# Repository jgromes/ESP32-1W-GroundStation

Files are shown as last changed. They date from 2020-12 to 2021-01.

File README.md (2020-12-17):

# ESP32-1W-GroundStation
ESP32-based LoRa ground station

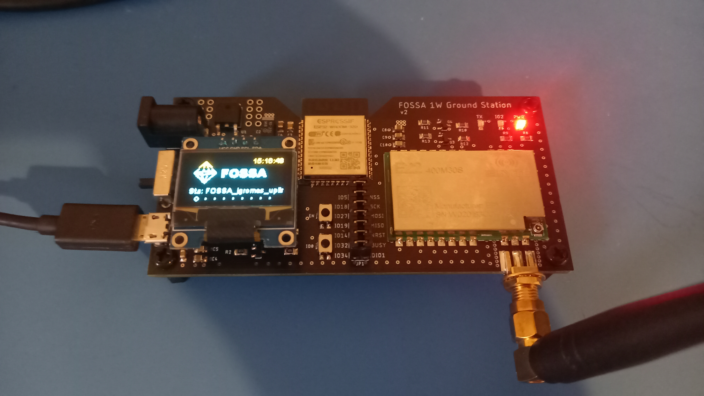
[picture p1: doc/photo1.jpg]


## Features:
* Fully compatible with https://github.com/G4lile0/ESP32-OLED-Fossa-GroundStation
* Radio: Ebyte E22-400M30S (http://www.ebyte.com/en/product-view-news.aspx?id=454)
  * SX1268 with TCXO
  * 1W external PA
  * Automatic Rx/Tx switching
  * IPX and SMA connectors
* OLED display
* Selectable power source (USB/external jack)
* Status LEDs: power, Rx/Tx, ESP32 IO2
* On-board USB/UART convertor

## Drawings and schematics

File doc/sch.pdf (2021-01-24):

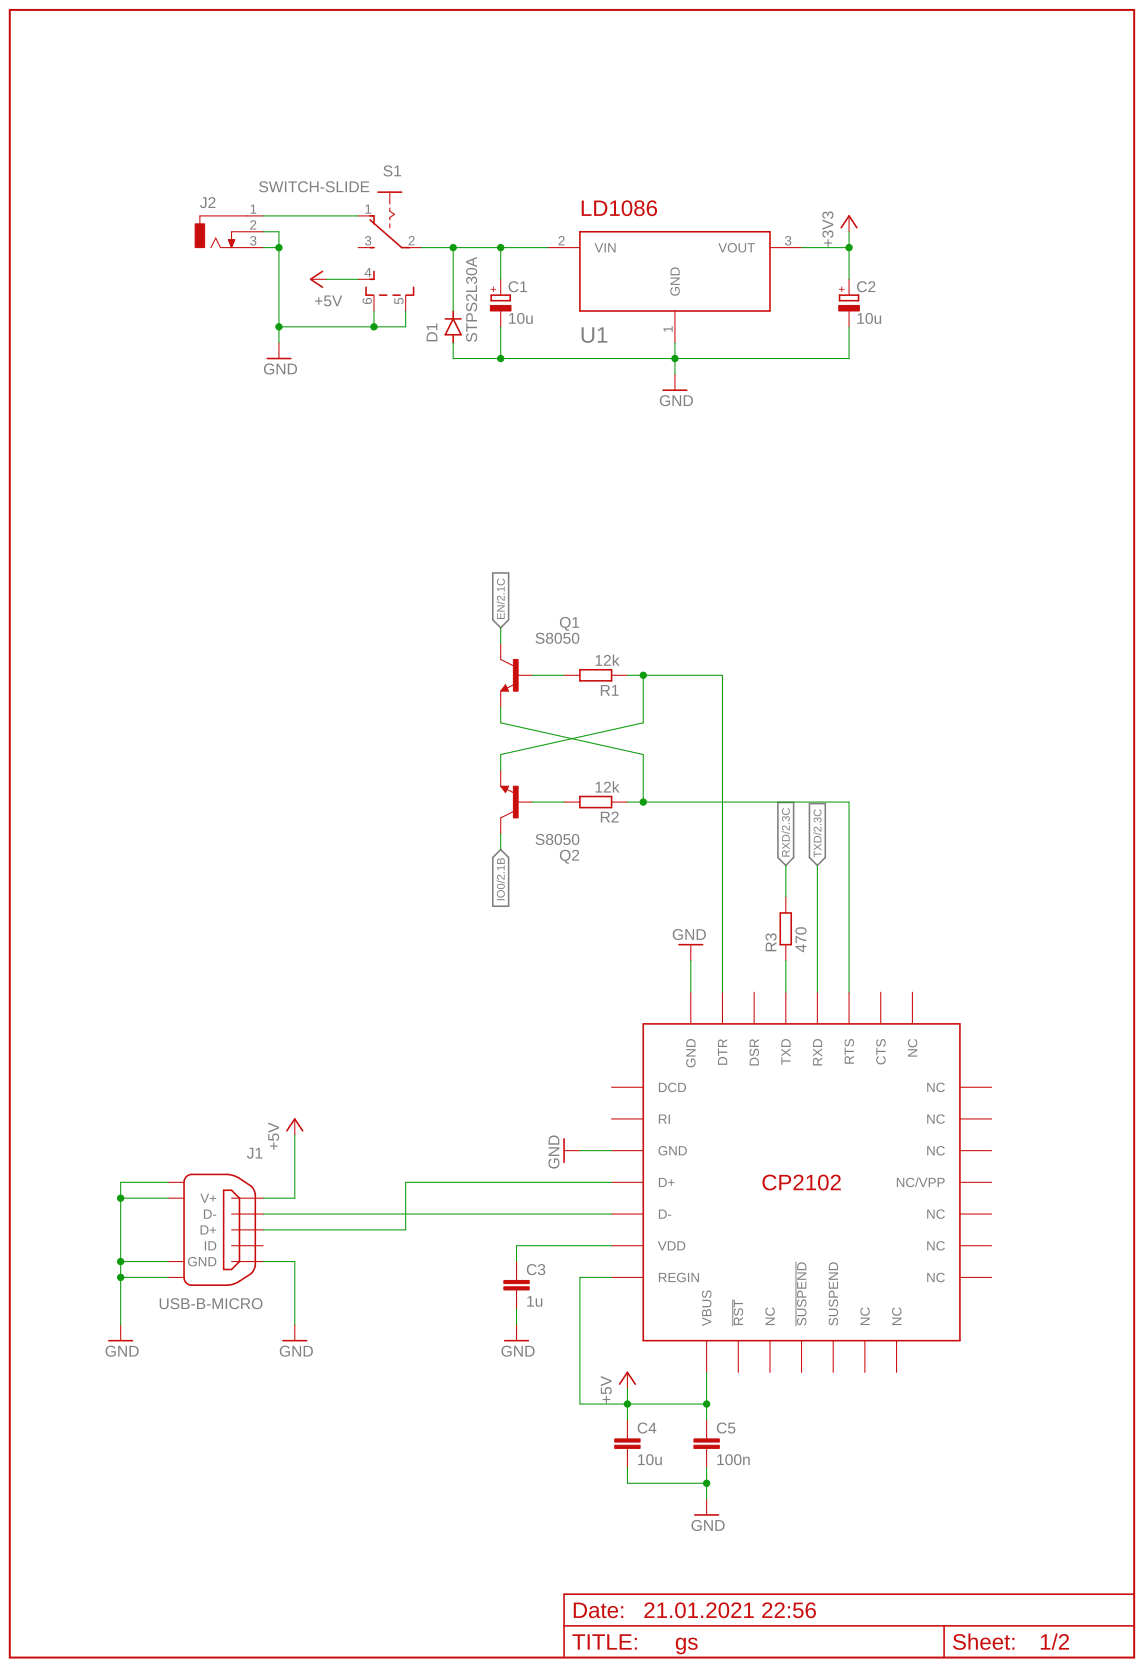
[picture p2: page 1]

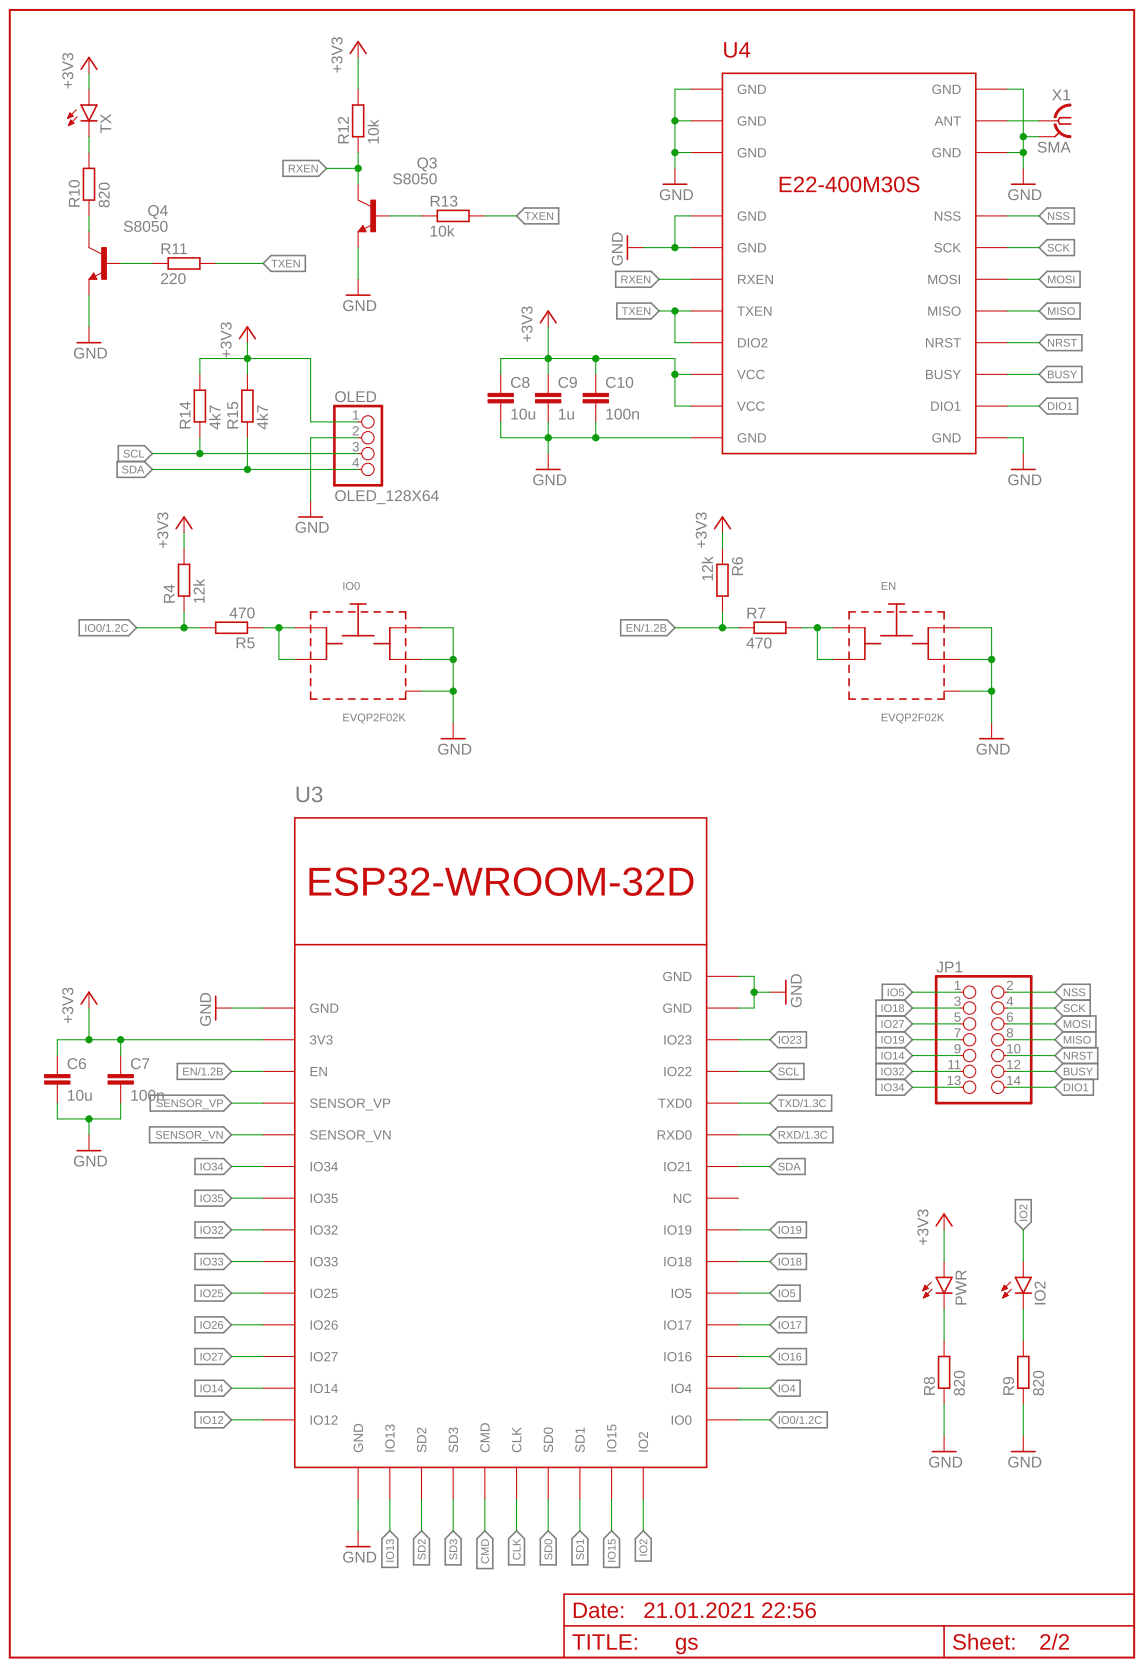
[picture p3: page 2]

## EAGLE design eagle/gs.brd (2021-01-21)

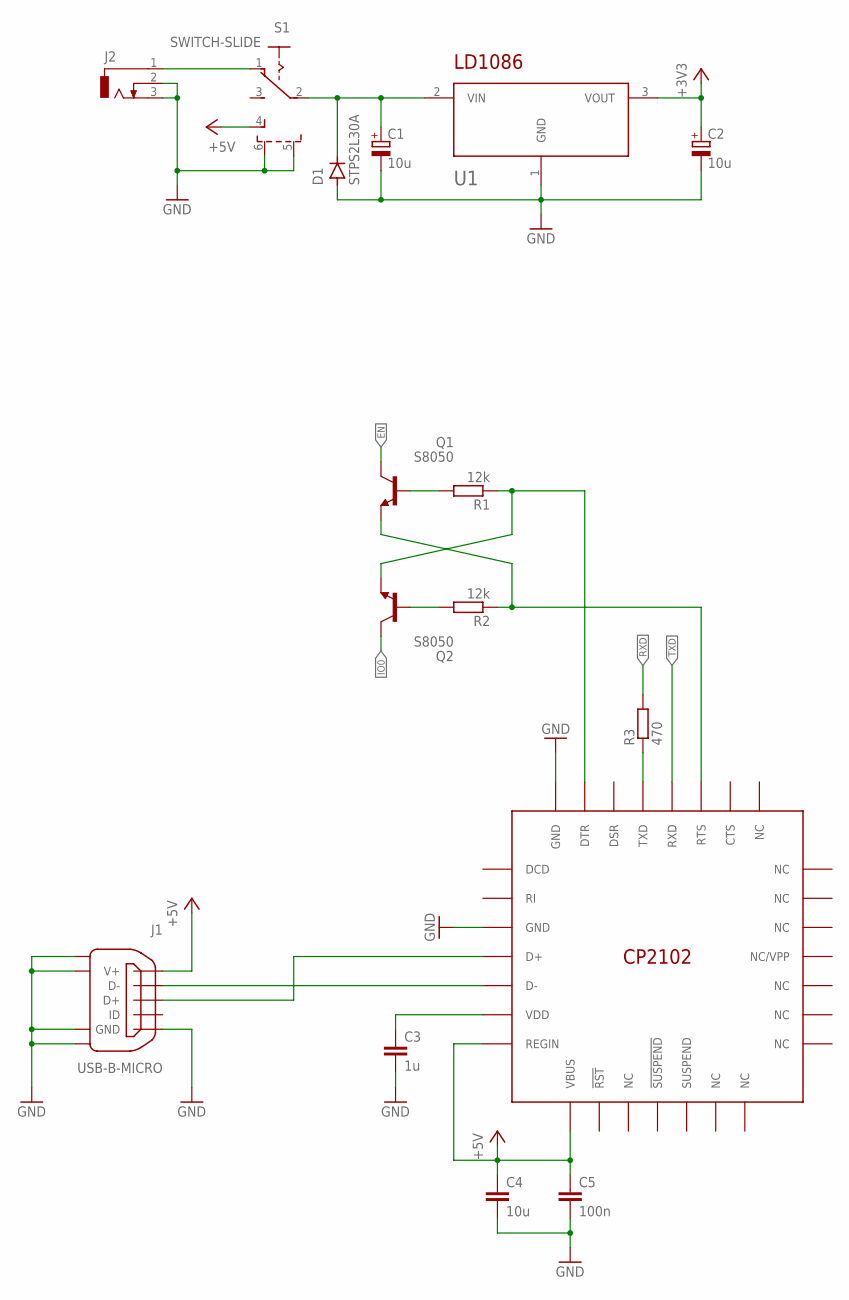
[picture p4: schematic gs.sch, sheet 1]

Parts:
C1, C2: 10u; SMC_C
C3: 1u; C0805
C4: 10u; C0805
C5: 100n; C0805
D1: STPS2L30A; DIOM4225X245N
J1: USB-B-MICRO
J2: DCJ0303
Q1, Q2: S8050; SOT95P237X110-3N
R1, R2: 12k; R0805
R3: 470; R0805
S1: SWITCH-SLIDE
U1: LD1086DT33TR; TO228P972X240-3N
U2: CP2102; QFN50P500X500X100-29T300N

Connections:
+3V3: C2.+, U1.3 (VOUT); also elsewhere on the board
+5V: C4.1, C5.1, J1.1 (V+), S1.4, U2.7 (REGIN), U2.8 (VBUS)
EN: Q1.3 (C); also elsewhere on the board
GND: C1.-, C2.-, C3.2, C4.2, C5.2, D1.2 (A), J1.5 (GND), J1.6, J1.7, J1.8, J1.9, J2.2, J2.3, S1.5 (S1), S1.6 (S2), U1.1 (GND), U2.3 (GND), U2.29 (GND); also elsewhere on the board
IO0: Q2.3 (C); also elsewhere on the board
unnamed: J1.2 (D-), U2.5 (D-)
unnamed: J1.3 (D+), U2.4 (D+)
unnamed: R3.1, U2.26 (TXD)
unnamed: Q1.1 (B), R1.2
unnamed: Q2.1 (B), R2.2
unnamed: Q2.2 (E), R1.1, U2.28 (DTR)
unnamed: Q1.2 (E), R2.1, U2.24 (RTS)
unnamed: C3.1, U2.6 (VDD)
unnamed: J2.1, S1.1
unnamed: C1.+, D1.1 (C), S1.2, U1.2 (VIN)
RXD: R3.2; also elsewhere on the board
TXD: U2.25 (RXD); also elsewhere on the board

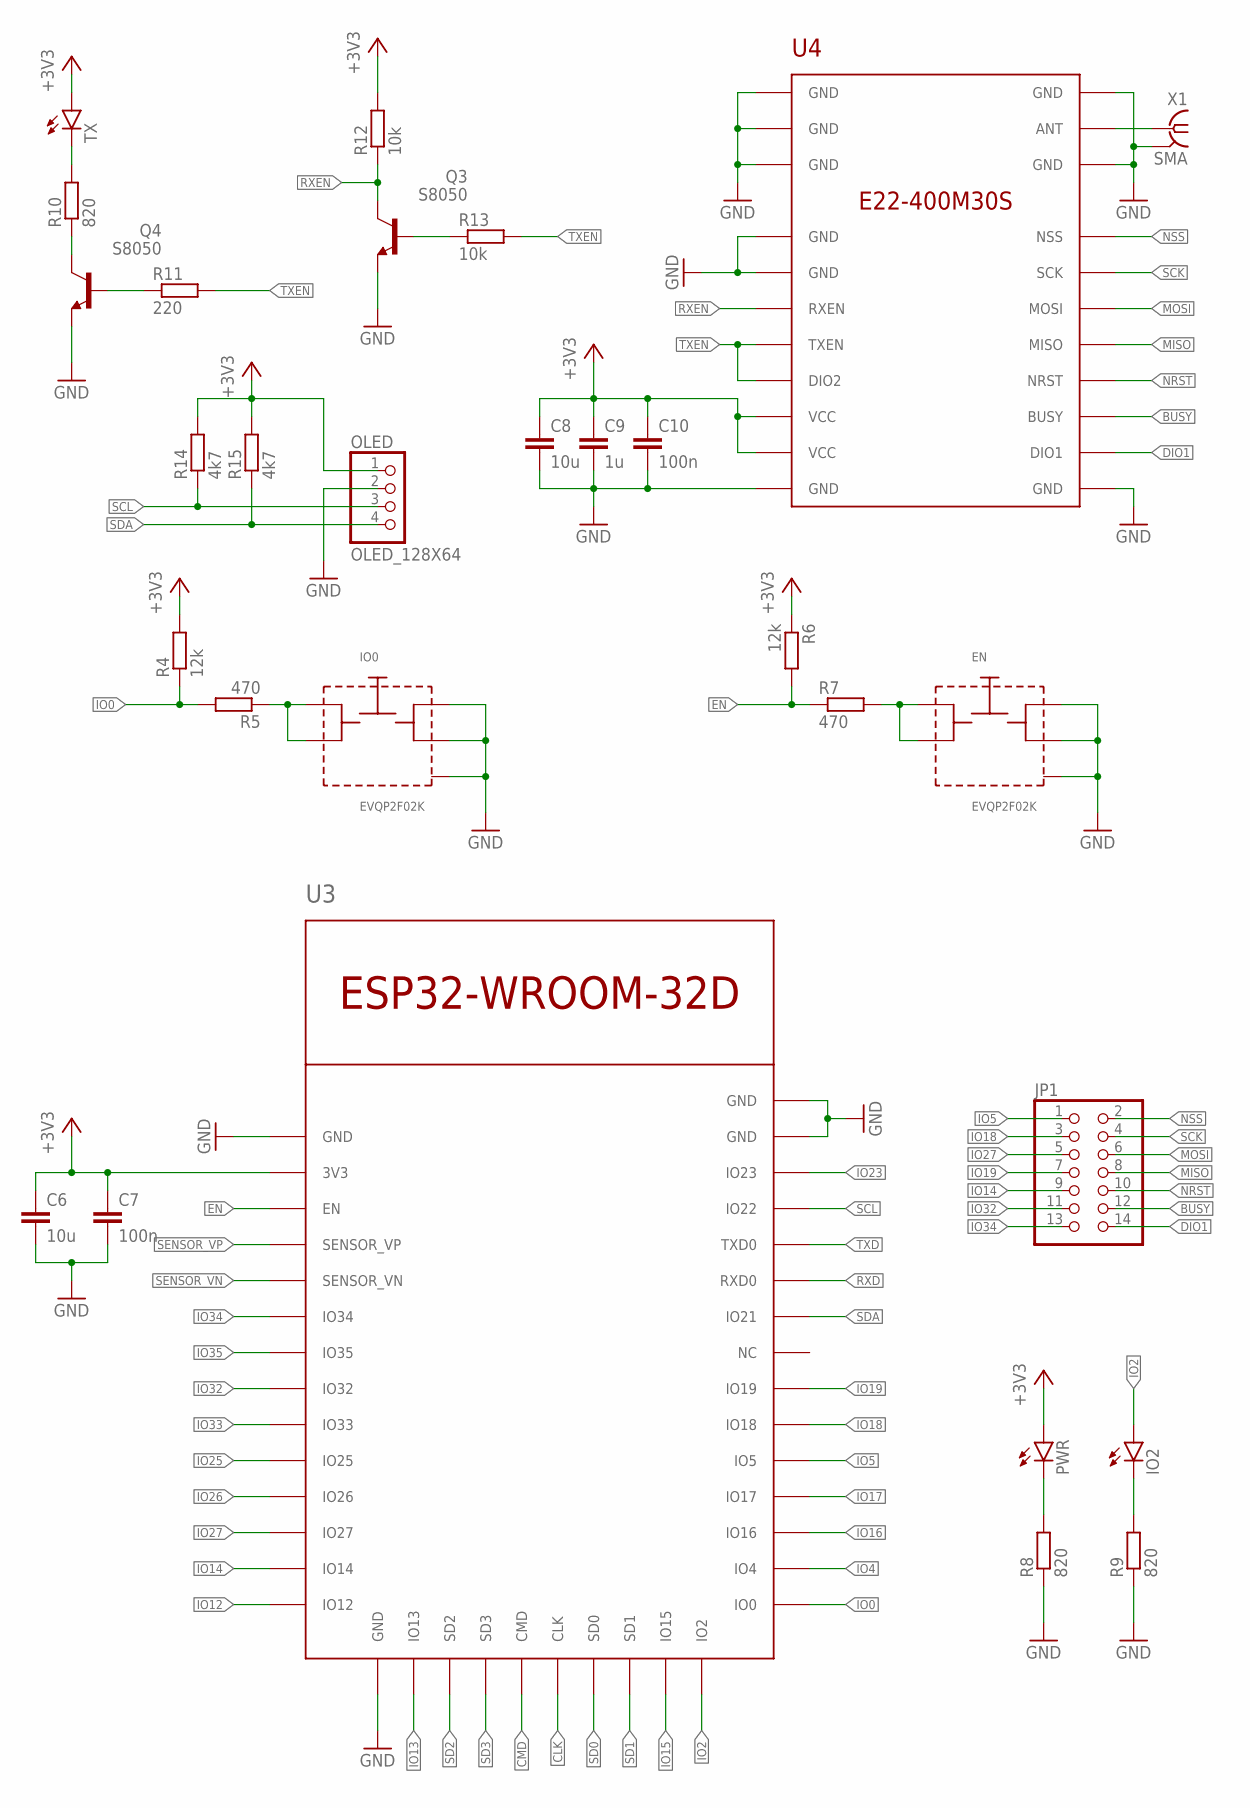
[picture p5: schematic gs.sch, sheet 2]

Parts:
C6, C8: 10u; C0805
C7, C10: 100n; C0805
C9: 1u; C0805
EN: EVQP2F02K
IO0: EVQP2F02K
IO2: LEDCHIP-LED0805; CHIP-LED0805
JP1: PINHD-2X7; 2X07
OLED: OLED_128X64
PWR: LEDCHIP-LED0805; CHIP-LED0805
Q3, Q4: S8050; SOT95P237X110-3N
R4, R6: 12k; R0805
R5, R7: 470; R0805
R8, R9, R10: 820; R0805
R11: 220; R0805
R12, R13: 10k; R0805
R14, R15: 4k7; R0805
TX: LEDCHIP-LED0805; CHIP-LED0805
U3: ESP32-WROOM-32D; ESP32-SOLO-1
U4: E22-400M30S
X1: SMA

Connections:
+3V3: C6.1, C7.1, C8.1, C9.1, C10.1, OLED.1, PWR.A, R4.2, R6.1, R12.2, R14.2, R15.2, TX.A, U3.2 (3V3), U4.9 (VCC), U4.10 (VCC); also elsewhere on the board
BUSY: JP1.12, U4.14 (BUSY)
CLK: U3.20 (CLK)
CMD: U3.19 (CMD)
DIO1: JP1.14, U4.13 (DIO1)
EN: R6.2, R7.1, U3.3 (EN); also elsewhere on the board
GND: C6.2, C7.2, C8.2, C9.2, C10.2, EN.3, EN.4, EN.5, IO0.3, IO0.4, IO0.5, OLED.2, Q3.2 (E), Q4.2 (E), R8.1, R9.1, U3.1 (GND), U3.15 (GND), U3.38 (GND), U3.39 (GND), U4.1 (GND), U4.2 (GND), U4.3 (GND), U4.4 (GND), U4.5 (GND), U4.11 (GND), U4.12 (GND), U4.20 (GND), U4.22 (GND), X1.G@1 (2), X1.G@2 (2), X1.G@3 (2), X1.G@4 (2); also elsewhere on the board
IO0: R4.1, R5.2, U3.25 (IO0); also elsewhere on the board
IO2: IO2.A, U3.24 (IO2)
IO4: U3.26 (IO4)
IO5: JP1.1, U3.29 (IO5)
IO12: U3.14 (IO12)
IO13: U3.16 (IO13)
IO14: JP1.9, U3.13 (IO14)
IO15: U3.23 (IO15)
IO16: U3.27 (IO16)
IO17: U3.28 (IO17)
IO18: JP1.3, U3.30 (IO18)
IO19: JP1.7, U3.31 (IO19)
IO23: U3.37 (IO23)
IO25: U3.10 (IO25)
IO26: U3.11 (IO26)
IO27: JP1.5, U3.12 (IO27)
IO32: JP1.11, U3.8 (IO32)
IO33: U3.9 (IO33)
IO34: JP1.13, U3.6 (IO34)
IO35: U3.7 (IO35)
MISO: JP1.8, U4.16 (MISO)
MOSI: JP1.6, U4.17 (MOSI)
unnamed: PWR.C, R8.2
unnamed: IO2.C, R9.2
unnamed: EN.1, EN.2, R7.2
unnamed: IO0.1, IO0.2, R5.1
unnamed: U4.21 (ANT), X1.1
unnamed: Q4.3 (C), R10.1
unnamed: Q3.1 (B), R13.1
unnamed: Q4.1 (B), R11.1
unnamed: R10.2, TX.C
NRST: JP1.10, U4.15 (NRST)
NSS: JP1.2, U4.19 (NSS)
RXD: U3.34 (RXD0); also elsewhere on the board
RXEN: Q3.3 (C), R12.1, U4.6 (RXEN)
SCK: JP1.4, U4.18 (SCK)
SCL: OLED.3, R14.1, U3.36 (IO22)
SD0: U3.21 (SD0)
SD1: U3.22 (SD1)
SD2: U3.17 (SD2)
SD3: U3.18 (SD3)
SDA: OLED.4, R15.1, U3.33 (IO21)
SENSOR_VN: U3.5 (SENSOR_VN)
SENSOR_VP: U3.4 (SENSOR_VP)
TXD: U3.35 (TXD0); also elsewhere on the board
TXEN: R11.2, R13.2, U4.7 (TXEN), U4.8 (DIO2)

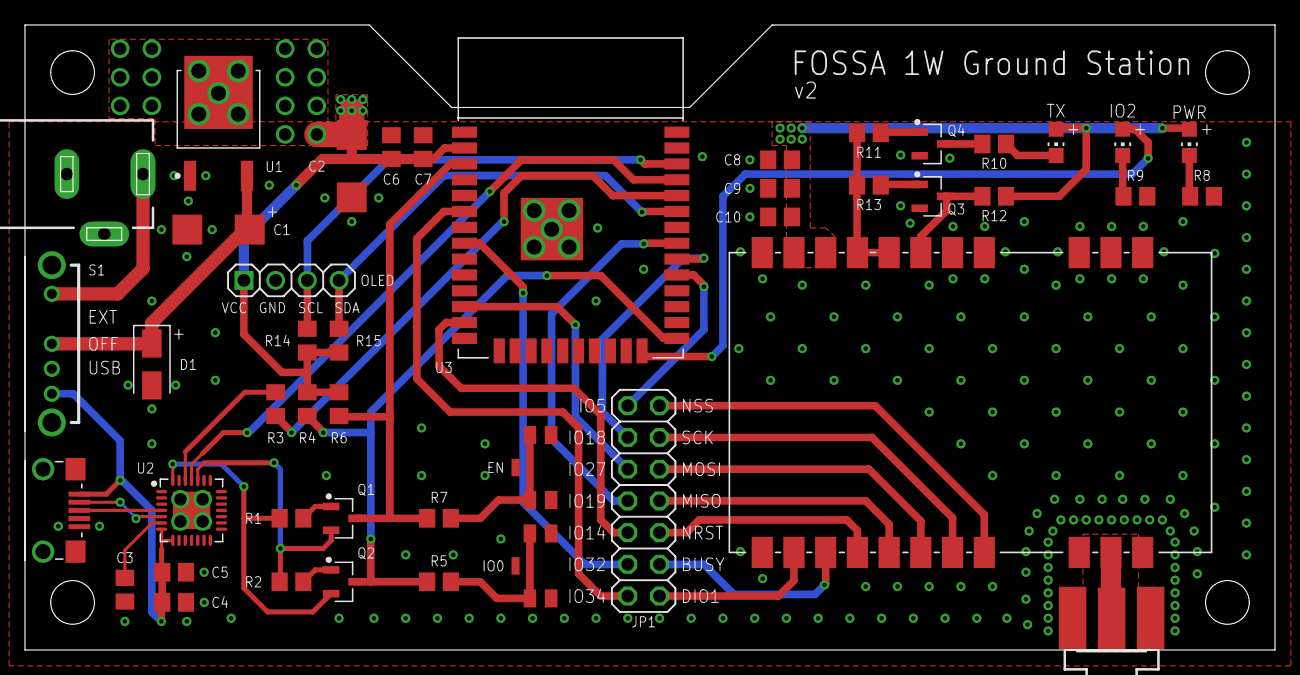
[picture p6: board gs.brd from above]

Board: 2 copper layers, 100.1 x 50.0 mm, 45 parts (0 on the bottom side), 45 nets.

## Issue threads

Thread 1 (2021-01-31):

CP2102 pin DTR or DSR?

K4KDR, 2021-01-31:
Hello!

Bob, N6RFM, has been a tremendous help to me in acquiring the parts and the custom PCB to build your project.  It has been great fun and a real challenge.

As I was reviewing the pin connections to the CP2102, a question has come up.

Across the top row, on the schematic (see image below), the 'DSR' pin (3rd from the left) is not used.

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

.
... however, on the PCB, it is the SECOND pin from the left that appears to be not used:

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

... could you please let us know which is correct, and what we should do to correct the situation (if any correction is needed)?

Many thanks!

-Scott,  K4KDR

jgromes, 2021-01-31:
It's actually the same pin -  DTR, pin 28 on the package. On the schematic, the left-most pin is the thermal pad, connected to GND.

K4KDR, 2021-01-31:
Thank you SO much for the reply!

I had not noticed that the schematic's top row took the liberty of displaying -8- connections while there are only 7 real pin connections.  So, as you said, that ground connection is not actually along that side of the device.

Appreciate the guidance!!

Closed 2021-01-31.

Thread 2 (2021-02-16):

USB connect/disconnect

K4KDR, 2021-02-16:
Hello!  Hoping to use the lessons learned from my first attempt at building this device, I used extraordinary caution when assembling my second attempt unit.  No detail was too small.  (I actually did component-level bench repair way back when... quite a few resume entries ago)

While we can never rule out an assembly problem, I wanted to share my result on the outside chance that it indicated something in particular.  When connecting the unit to the same USB cable that works perfectly fine for off-the-shelf ESP32's, my syslog loops through the following:

```
Feb 16 05:11:25 3010i5 kernel: [40601.552217] usb 1-1.3: new full-speed USB device number 106 using ehci-pci
Feb 16 05:11:26 3010i5 kernel: [40601.662018] usb 1-1.3: New USB device found, idVendor=10c4, idProduct=ea60, bcdDevice= 1.00
Feb 16 05:11:26 3010i5 kernel: [40601.662020] usb 1-1.3: New USB device strings: Mfr=1, Product=2, SerialNumber=3
Feb 16 05:11:26 3010i5 kernel: [40601.662021] usb 1-1.3: Product: CP2102 USB to UART Bridge Controller
Feb 16 05:11:26 3010i5 kernel: [40601.662022] usb 1-1.3: Manufacturer: Silicon Labs
Feb 16 05:11:26 3010i5 kernel: [40601.662022] usb 1-1.3: SerialNumber: 0001
Feb 16 05:11:26 3010i5 kernel: [40601.662921] cp210x 1-1.3:1.0: cp210x converter detected
Feb 16 05:11:26 3010i5 mtp-probe: checking bus 1, device 106: "/sys/devices/pci0000:00/0000:00:1a.0/usb1/1-1/1-1.3"
Feb 16 05:11:26 3010i5 mtp-probe: bus: 1, device: 106 was not an MTP device
Feb 16 05:11:26 3010i5 kernel: [40601.664955] usb 1-1.3: cp210x converter now attached to ttyUSB0
Feb 16 05:11:27 3010i5 snapd[830]: hotplug.go:199: hotplug device add event ignored, enable experimental.hotplug
Feb 16 05:11:27 3010i5 systemd[1]: Starting Manage ttyUSB0 for GPS daemon...
Feb 16 05:11:27 3010i5 gpsdctl: gpsd_control(action=add, arg=/dev/ttyUSB0)
Feb 16 05:11:27 3010i5 gpsdctl: reached a running gpsd
Feb 16 05:11:27 3010i5 systemd[1]: Started Manage ttyUSB0 for GPS daemon.
Feb 16 05:11:27 3010i5 upowerd[1403]: unhandled action 'bind' on /sys/devices/pci0000:00/0000:00:1a.0/usb1/1-1/1-1.3/1-1.3:1.0
Feb 16 05:11:28 3010i5 upowerd[1403]: unhandled action 'bind' on /sys/devices/pci0000:00/0000:00:1a.0/usb1/1-1/1-1.3
Feb 16 05:11:29 3010i5 ModemManager[812]: <info>  Couldn't check support for device '/sys/devices/pci0000:00/0000:00:1a.0/usb1/1-1/1-1.3': not supported by any plugin
Feb 16 05:11:34 3010i5 kernel: [40609.706944] usb 1-1.3: USB disconnect, device number 106
Feb 16 05:11:34 3010i5 kernel: [40609.707152] cp210x ttyUSB0: cp210x converter now disconnected from ttyUSB0
Feb 16 05:11:34 3010i5 kernel: [40609.707171] cp210x 1-1.3:1.0: device disconnected
Feb 16 05:11:34 3010i5 systemd[1]: Stopping Manage ttyUSB0 for GPS daemon...
Feb 16 05:11:34 3010i5 upowerd[1403]: unhandled action 'unbind' on /sys/devices/pci0000:00/0000:00:1a.0/usb1/1-1/1-1.3/1-1.3:1.0
Feb 16 05:11:34 3010i5 gpsdctl: gpsd_control(action=remove, arg=/dev/ttyUSB0)
Feb 16 05:11:34 3010i5 gpsdctl: reached a running gpsd
Feb 16 05:11:34 3010i5 systemd[1]: Stopped Manage ttyUSB0 for GPS daemon.
Feb 16 05:11:35 3010i5 upowerd[1403]: unhandled action 'unbind' on /sys/devices/pci0000:00/0000:00:1a.0/usb1/1-1/1-1.3
Feb 16 05:11:36 3010i5 compiz[1408]: [ALSOFT] (EE) Failed to set real-time priority for thread: Operation not permitted (1)
```

... by chance does anything there suggest what might be wrong?  FYI, one time it actually stayed "alive" long enough for me to upload code via the Arduino IDE and in the serial monitor, I got one quick iteration of my code's user menu.

Note that I am only using USB power.  While this works perfectly fine for any other device I use, do you think it might possibly be helpful here if I powered the unit externally?

Many thanks!

-Scott,  K4KDR

K4KDR, 2021-02-16:
Just to follow-up, I have noticed that the CP2102 chip gets EXTREMELY hot.  I removed D1 in case I had installed that backwards but with D1 removed, the same syslog errors occur and CP2102 (U2) still gets hot.

jgromes, 2021-02-16:
The overheating issue is very strange, it doesn't do that on my board. How long does it take to start overheating? Can you rule out shorts on the QFN package? Also, are you using CP2102 or CP2102N? Apparently, those two are quite different.

Using only USB power should be fine for startup, it might not be enough when transmitting at 1 W but that's not the case now.

The USB/UART converter and reset circuit is copied from NodeMCU, so I hoped it would work. Which ESP32s did you try?

K4KDR, 2021-02-16:
The overheating is immediate.  FYI, the first components installed were the USB jack and CP2102.  Connecting to the computer via USB with ONLY those two components installed gave a proper "USB device found" type of message in syslog, so I felt confident to continue the build.  No overheating was noticed at that point.

I continued this "syslog" type of testing throughout the build.  Everything was stable until the last few components were installed.  They were the SMA jack, pin header, slide switch, R3 / R5 / R7, and R14 / R15.

If no smoking gun is identified, I can certainly work backwards removing the last few components to see if the issue stops.  I would like to think I can omit the SMA jack from consideration, but the other components might be telling.

As for those components you asked about, the CP2102 is:  https://www.mouser.com/ProductDetail/634-CP2102-GM/

... and the ESP32 is:  https://www.mouser.com/ProductDetail/356-ES32WROOM32D16MB/

If I have used an incorrect CP2102, that would almost be "good" news - at least I would have an explanation.

Thank you so much for your time!

jgromes, 2021-02-16:
Let's go through it then, back to front:

* R14/15 are I2C pullups, so that's most likely not related
* R7 is just a serial resistor on ESP32's RX - again, doesn't seem like the culprit
* R3/5 are serial resistors that connect to the reset and bootloader buttons. That one looks more interesting, what buttons did you use? If they're always shorted to the ground, it could mess up the BJT autoreset switches
* the slide switch connects the CP2102 to power, so that one will always be suspicious
* pin header doesn't seem related
* SMA jack also doesn't

The CP2102 should be the correct one, as well as the ESP32.

K4KDR, 2021-02-16:
I was hoping I had chosen the wrong CP2102... at least that would be easy to correct!

Very well, thank you so much for the detailed part functionality review.  I will start removing items until I return to a device that will connect to the computer in a stable fashion -- and without excess heat.

By chance do you have a high-resolution picture of a completed board **without** the OLED installed?  It would be helpful to verify the orientation of some components obscured by that display... D1 in particular.  There is a faint 'line' on one end of D1 and I am not certain whether the 'line' should face U1 or U2.

Thanks!

jgromes, 2021-02-16:
OK, that should be the exact same as mine, so that theory is busted then.

Here's a picture of the area beneath the dispplay, hope it helps. The diode is there just for reverse-voltage protection, so if it's mounted backwards, it still doesn't explain the overheating issue.

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

K4KDR, 2021-02-16:
Thank you!  I had D1 oriented correctly, so I'll re-install it.
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
K4KDR, 2021-02-17:
An update....

Noticed the following scrolling non-stop in the Serial Monitor window in VSCode:

```
----------------------------
rst:0x10 (RTCWDT_RTC_RESET),boot:0x13 (SPI_FAST_FLASH_BOOT)
flash read err, 1000
ets_main.c 371
ets Jun  8 2016 00:22:57
-----------------------------
```

jgromes, 2021-02-17:
Seems like an issue with the ESP32 flash module. Could you post the full output of esptool?

K4KDR, 2021-02-18:
Glad to!

 Is there some particular argument that might help you?  If I just run

 `esptool.py --port /dev/ttyUSB0`

it returns the list of additional options & arguments that are available

jgromes, 2021-02-18:
Nothing in particular, just the output from uploading via esptool (even in Arduino IDE).

K4KDR, 2021-02-18:
Very good - thank you!  Here is what I get when attempting to upload from VSCode:

[2021-02-18--k4kdr--esptool-upload-error.txt](https://github.com/jgromes/ESP32-1W-GroundStation/files/6004292/2021-02-18--k4kdr--esptool-upload-error.txt)

jgromes, 2021-02-19:
After going through a couple issues on esptool GitHub, I think this is most likely faulty hardware again. This seems to be supported by the esptool output:

```
Warning: Could not auto-detect Flash size (FlashID=0xffffff, SizeID=0xff), defaulting to 4MB
```

0xFF is a very typical output of a faulty SPI. My guess is that either something got damaged with the shorted CP2102, or there's some short or cold joint on the ESP32.

As a last check, could you try running `espefuse.py --port PORT summary` (where PORT is the serial port ESP32 is connected to)? Apparently this thing can also happen if the fuses aren't set correctly.

K4KDR, 2021-02-19:
I have also been researching this and the internet is flooded with reports of similar issues/errors.  Apparently there is some combination of circumstances that makes this type of thing very common with ESP32s.

There seem to be many references to `GPIO-2` possibly having a role in whether or not an ESP32 can be programmed successfully, but I'm not clear on that.

I saw many references to the `espefuse` command but have no idea what a "fuse" is in the ESP32 world.  The output of that command from my build is attached.  Many thanks!!

[2021-02-19--k4kdr--espefuse-output.txt](https://github.com/jgromes/ESP32-1W-GroundStation/files/6011641/2021-02-19--k4kdr--espefuse-output.txt)

jgromes, 2021-02-21:
Looking over the efuses, I don't see anything that stands out.

GPIO2 is used as LED indicator pin, I guess you could try to remove R9 to isolate it, but I don't think it's going to make a difference. So I'm afraid this really does look like a hardware fault in the ESP32 module.

K4KDR, 2021-02-21:
Thanks so much!!  I'll remove R9 in case GPIO2 is a factor.  If nothing changes, then I'll try another ESP32 module.

Will report the results!

K4KDR, 2021-02-22:
Very grateful for your patience to walk me through this fun project!    Removing R9 did not help, so I removed the ESP32 and installed a new one.

The device now accepts programming both from VSCode and the Arduino IDE!

Could you please confirm the **pin assignments** for this Ebyte 400M30S module?   I have tried several combinations that I thought were correct, but get:

`Failed to initialize radio, code: -2`

From the user manual for this device, if I understand correctly this is an **SX1268** chip, is that right?

Finally, by chance is there any code available to "test" the various aspects of this build?  I mean, something more simple than the more complex repositories that add so many other variables into the equation?

Thanks!

K4KDR, 2021-02-22:
Follow-up... using the new BETA tinyGS code, I seem to be ok.  Your custom 1W board is on the pick list using the initial 192.168.4.1 wi-fi connection, so that got me properly configured.

Further, I found that same listing in the code so that should provide what I need in regard to pin assignments (for other uses of this device)

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

... so thank you again.  I used the "P" key available using the tinyGS code and confirmed over-the-air transmission looking at an SDR waterfall.  So, all is well so far.

jgromes, 2021-02-22:
The pin assignment for the LoRa module can also be seen on the PCB itself, next to the pin header. And yes, Ebyte 400M30S is using SX1268 as the transceiver.

Since it looks like the issue is now resolved, I'm closing this. I also created #3 with a list of improvements to make the design a bit easier to assemble, so if you have any more feedback, it would be great if you could place it in that issue. Thanks!

Closed 2021-02-22.

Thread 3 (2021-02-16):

Improvements for v3

jgromes, 2021-02-16:
* Pads for other high-power LoRa modules
* Pads for OLEDs with different pinouts

K4KDR, 2021-02-25:
My `#1` vote would be for a nice solid **USB-B jack** instead of the micro-USB.  Installation difficulty aside, it seems like every device that I own with a micro-USB feels like it could break at any moment.

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

jgromes, 2021-02-25:
The micro USB port used here should actually be pretty solid, since it has THT "stubs" that fix it mechanically. But you're right that most micro USBs are entirely SMD and it's very easy to rip them off the PCB.

Come to think of it, we already have a DC power jack on the board, which is similar in size, so there's really no upside to using micro-USB.

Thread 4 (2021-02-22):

Configure TX power = 30 dbm?

K4KDR, 2021-02-22:
With a working 1W custom ESP32/LoRa board now (thanks to you & Bob-N6RFM!), I noticed that the default tinyGS "Power" parameter (5 dbm) did not take advantage of this device's power output capability.

Using the "Configure Parameters" screen on the tinyGS web GUI (direct LAN IP connection to the device), I entered a value of "**30**" on the Modem Startup line.
.
.
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

.

However, after applying it, an error appears on the serial monitor:

` failed, code 4294967283`

... reviewing the tinyGS code (including libraries), I see the following comment in "lib/RadioLib/src/modules/SX126x/SX1268.h":

` \brief Sets output power. Allowed values are in range from -9 to 22 dBm.`

... indeed, the largest value that I can enter (with no error) on the 'Modem Startup' line in the web GUI is "22"

What steps are required to allow for a value of 30 dbm (i.e., 1W) to be used in this context?

Thanks!

jgromes, 2021-02-22:
You can't enter 30 dBm directly into RadioLib configuration methods, since those are limited by the SX1268 limitations, in this case by the maximum output of the internal PA, which is 22 dBm.

Ebyte 400M30S has an external PA, labeled as H0606E - some Chinese wunderwaffe. Googling a bit yields this datasheet: https://e2e.ti.com/cfs-file/__key/communityserver-discussions-components-files/156/RELL-_2D00_-LDMOS.pdf

According to that, it should have a 19 dB gain (up until 13 dBm input), so to set 30 dBm on the output of the module, you have to set 11 dBm as the output from SX1268. I'm still trying to verify those numbers with an actual RF power meter, since this sort of parts always makes me suspicious.

K4KDR, 2021-02-28:
Hello!

Any update on the proper way to use full TX power?

I see that the limits can be changed in `/lib/RadioLib/src/modules/SX126x/SX1268.h` ... but I don't have a watt meter to verify the device's output if it's set to '30' after adjusting that upper limit setting.

Thanks!

jgromes, 2021-02-28:
As per my previous message, you don't set the SX1268 power output to 30 dBm when using the ebyte module. Instead, you have to set to the SX1268 power output in such a way that the external PA will output 30 dBm. The PA gain is 19 dB, so to get 30 dBm total power, you have to set SX1268 power to 11 dBm by calling `setOutputPower(11);`.

K4KDR, 2021-02-28:
Ah, thanks so much!   You had mentioned doing a verification to see if that really resulted in the desired max output, so I didn't know if that had been possible to check on yet.

Appreciate everything!

jgromes, 2021-02-28:
Unfortunately not yet, I don't have access to a good RF power meter at the moment due to lockdown-induced logistics issues.

farmaceuta777, 2021-06-06:
what is the smallest gain of these modules? (max is 30db (set 11) and min?

SlitheringMule, 2023-06-09:
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

If you set SX1268 output greater than 11dBm does it fry the board?

jgromes, 2023-06-10:
@SlitheringMule it shouldn't, you just won't get much extra gain. You're also risking compromising the signal integrity, since you're out of the linear region of the gain curve.

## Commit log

2020-12-17 Added v2 Eagle files + Gerbers
    [gs.brd, gs.sch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]
2021-01-21 Fixed ESP32-SOLO-1 used instead of ESP32-WROOM-32D
    [gs.brd, gs.sch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]
2021-01-24 Added schematic as PDF
